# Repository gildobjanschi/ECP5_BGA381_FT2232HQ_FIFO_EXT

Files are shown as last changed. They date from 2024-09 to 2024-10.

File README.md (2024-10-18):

# Extension board for ECP5_BGA381_FT2232HQ_FIFO
This is an extension board for the [ECP5_BGA381_FT2232HQ_FIFO](https://github.com/gildobjanschi/ECP5_BGA381_FT2232HQ_FIFO) board. It is used to validate the main board design and to provide audio output connectors for I2S (HDMI) and SPDIF (Coaxial).

## Software
The bringup software that supports this board is located in the main board [ECP5_BGA381_FT2232HQ_FIFO](https://github.com/gildobjanschi/ECP5_BGA381_FT2232HQ_FIFO/tree/main/hdl_loopback) project. The [host software](https://github.com/gildobjanschi/ECP5_BGA381_FT2232HQ_FIFO/tree/main/host_loopback) is a simple application for testing the FIFO interface.

## Project Status
The board has been submitted to manufacturing to PCBWay.

[Schematic PDF](https://github.com/gildobjanschi/ECP5_BGA381_FT2232HQ_FIFO_EXT/blob/main/kicad/ECP5_Ext.pdf)

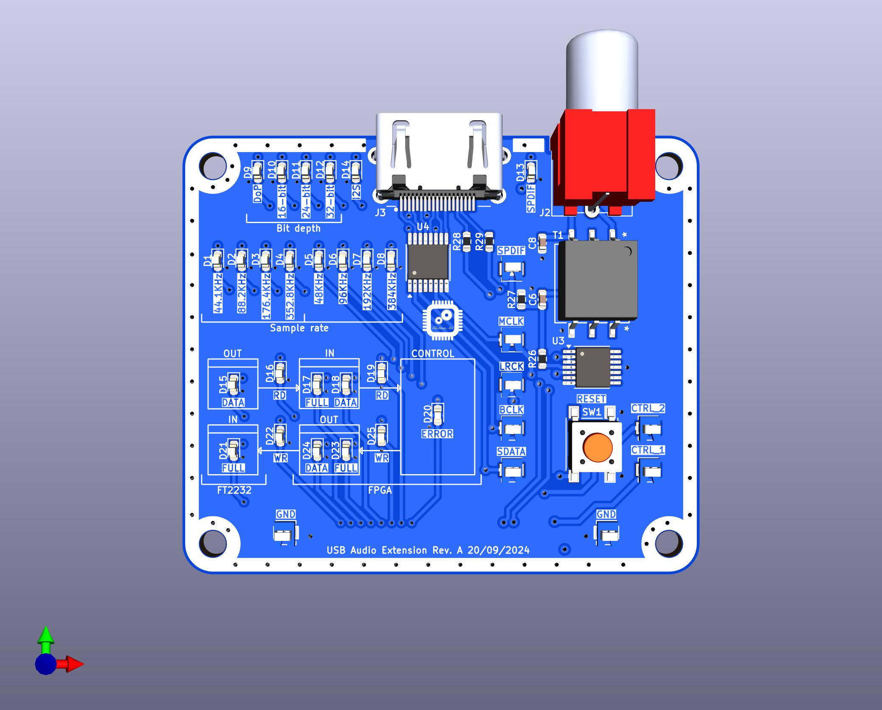
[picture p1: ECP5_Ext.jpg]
Board rendering


## How To setup KiCAD
Checkout the KiCAD project and open it. In the Configure Paths dialog add: Name: ECP5_BGA381_FT2232HQ_FIFO_EXT and Path: "The full path to the GitHub directory"/GitHub/ECP5_BGA381_FT2232HQ_FIFO_EXT

In the Manage Symbol Libraries click the Project Specific Libraries tab and add: Name: ECP5_BGA381_FT2232HQ_FIFO_EXT and Library Path: ${ECP5_BGA381_FT2232HQ_FIFO_EXT}/symbols/Symbols.kicad_sym

In the Manage Footprint Libraries click the Project Specific Libraries tab and add: Name: ECP5_BGA381_FT2232HQ_FIFO_EXT and Library Path: ${ECP5_BGA381_FT2232HQ_FIFO_EXT}/footprints/Footprints.pretty

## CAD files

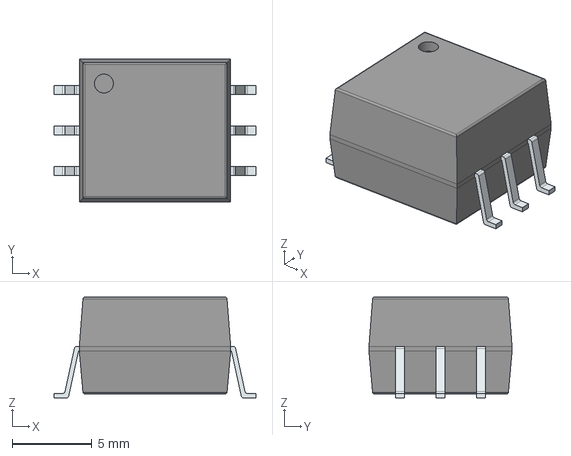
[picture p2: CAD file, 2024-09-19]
3dmodels/DA101JC.stp
12.7 x 9.00 x 6.35 mm
PinsArrayLR

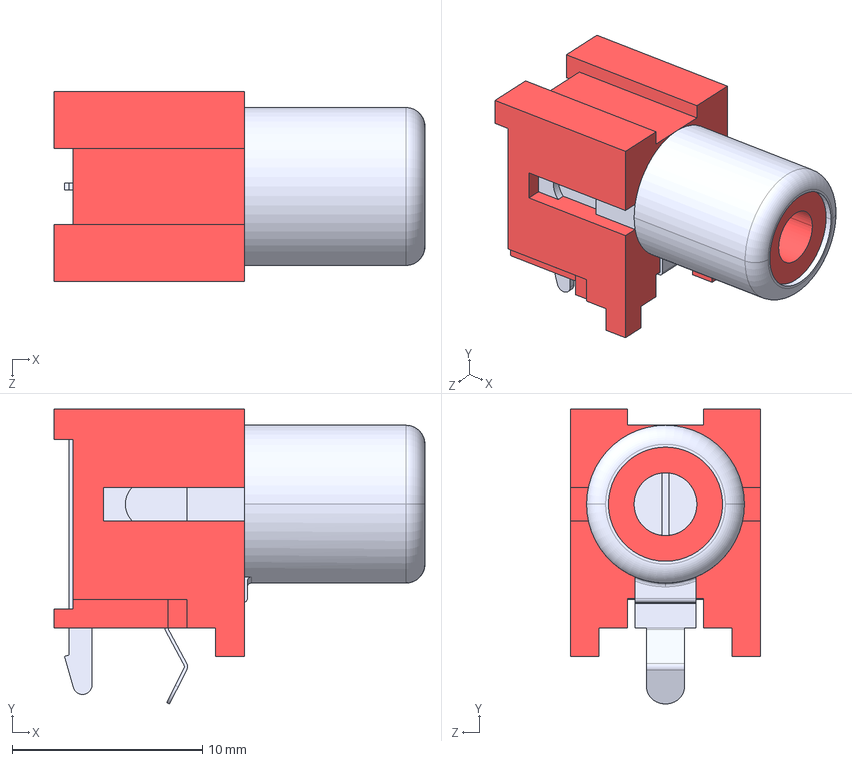
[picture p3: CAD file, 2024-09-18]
3dmodels/RCJ-042.step
19.5 x 15.5 x 10.0 mm

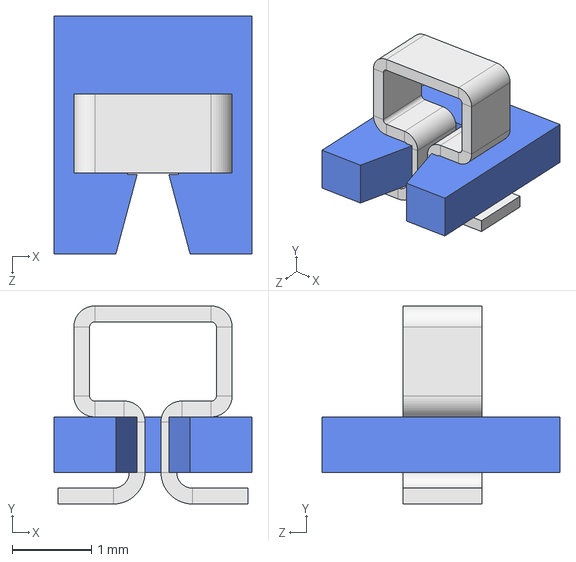
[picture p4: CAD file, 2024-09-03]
3dmodels/5197TR.step
2.50 x 2.50 x 3.00 mm
5197_insulation
5190_assembled contact

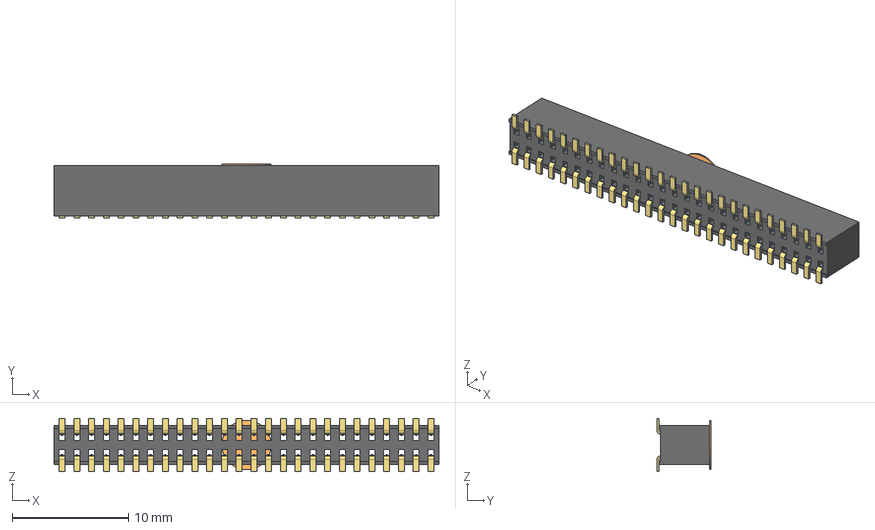
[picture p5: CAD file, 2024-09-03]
3dmodels/FLE-126-01-G-DV-K-TR.stp
33.1 x 4.67 x 4.59 mm
FLE-126-01-DV_socket
C-96-01-26-DV
K-DOT-0.1675-0.281-0.005_polyamide_pick

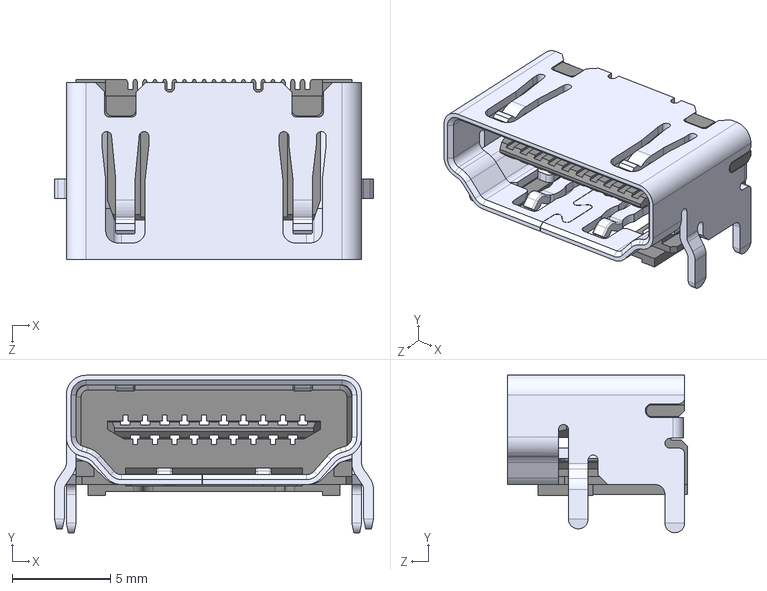
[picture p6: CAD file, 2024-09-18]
3dmodels/10029449-001RLF.step
16.2 x 8.00 x 9.15 mm

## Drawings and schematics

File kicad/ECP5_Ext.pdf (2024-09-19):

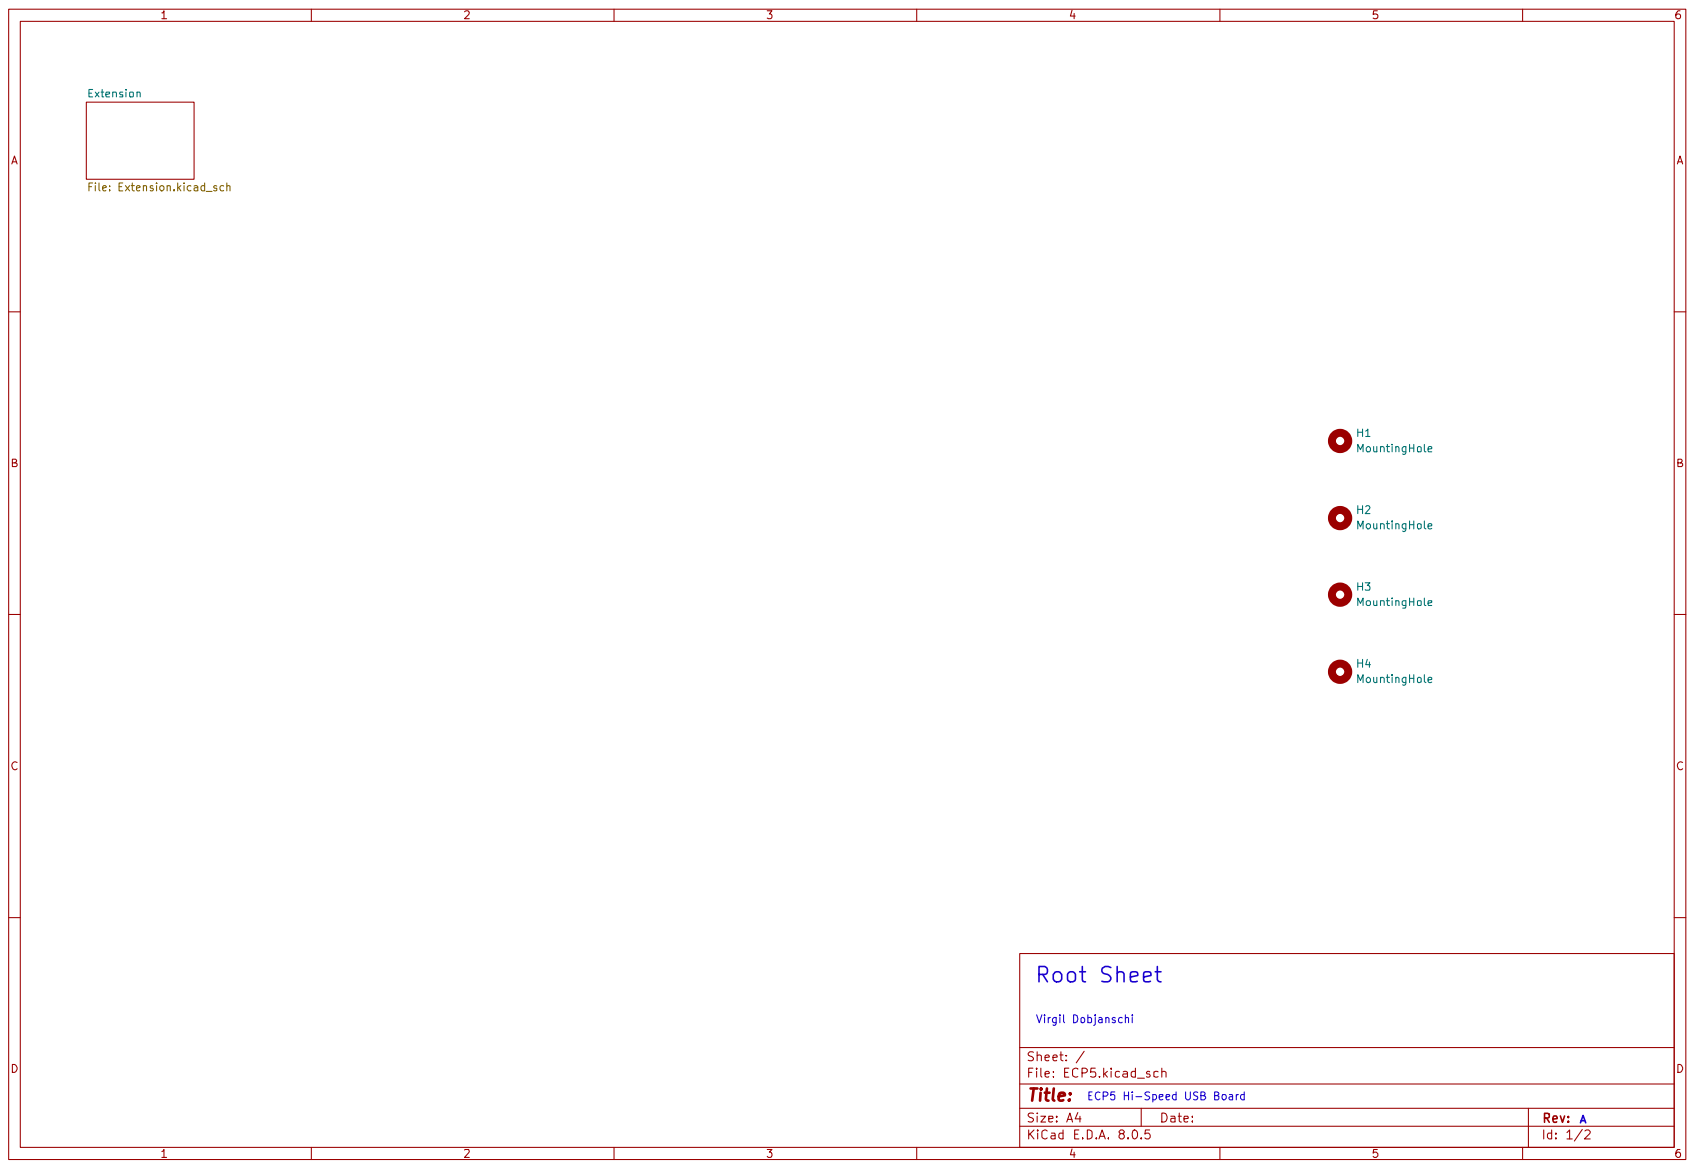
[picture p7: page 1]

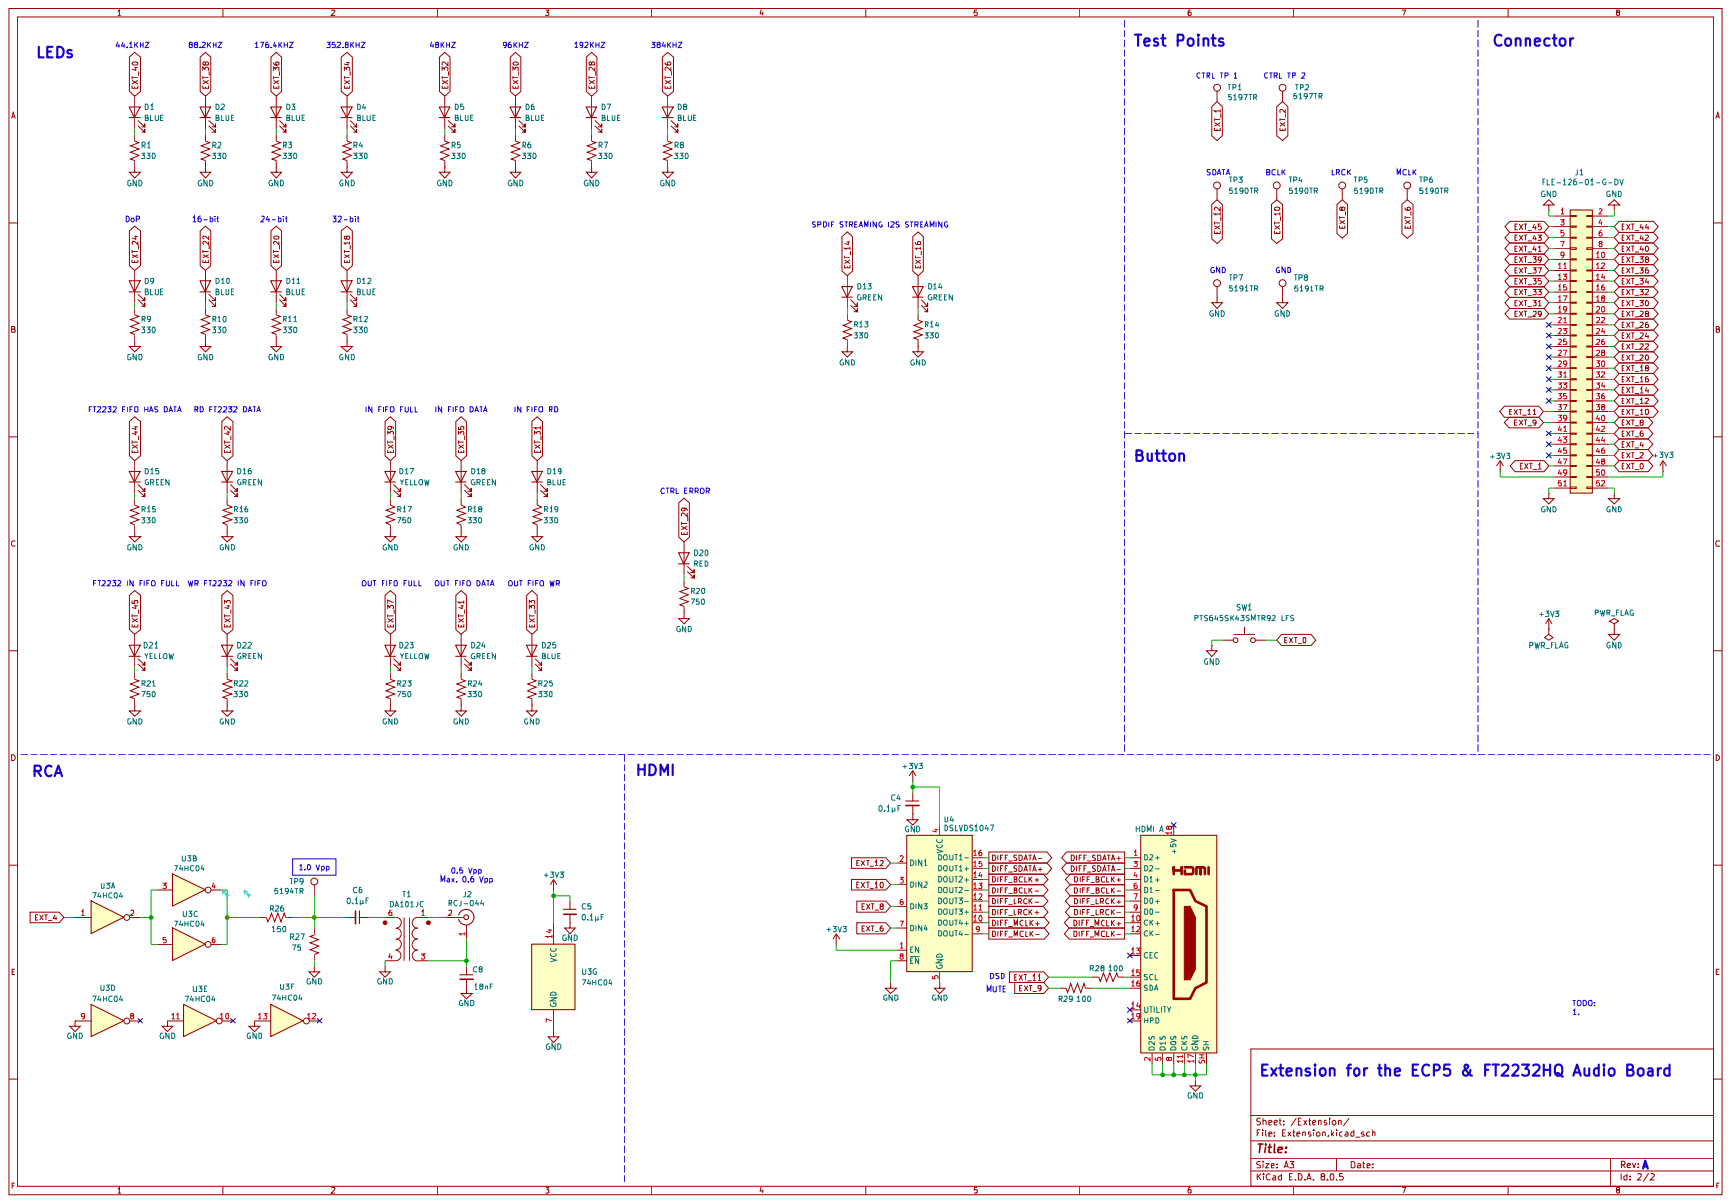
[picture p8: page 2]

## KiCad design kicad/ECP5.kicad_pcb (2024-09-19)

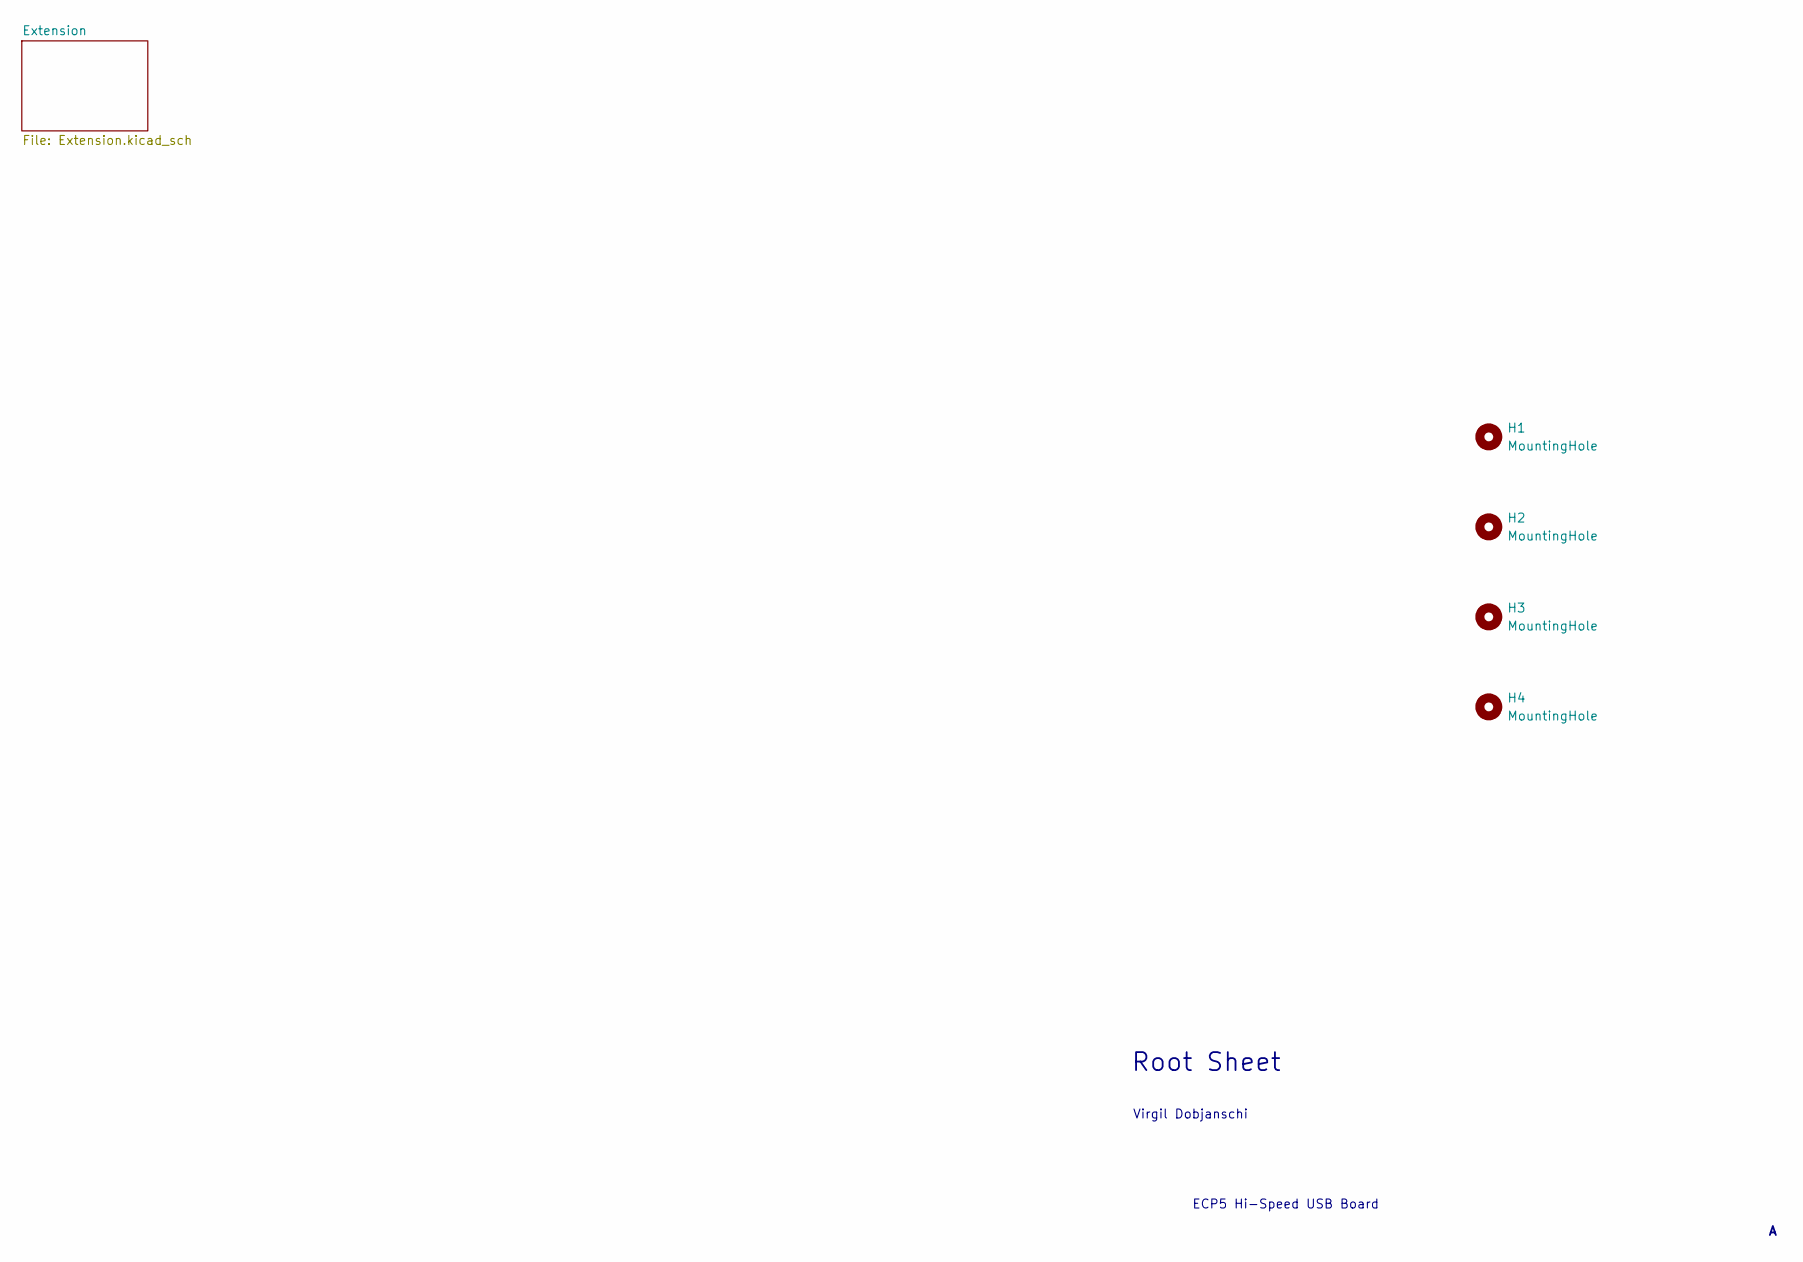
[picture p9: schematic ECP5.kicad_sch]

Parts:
H1, H2, H3, H4: MountingHole; MountingHole_3.2mm_M3

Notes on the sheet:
ECP5 Hi-Speed USB Board
Root Sheet
Virgil Dobjanschi

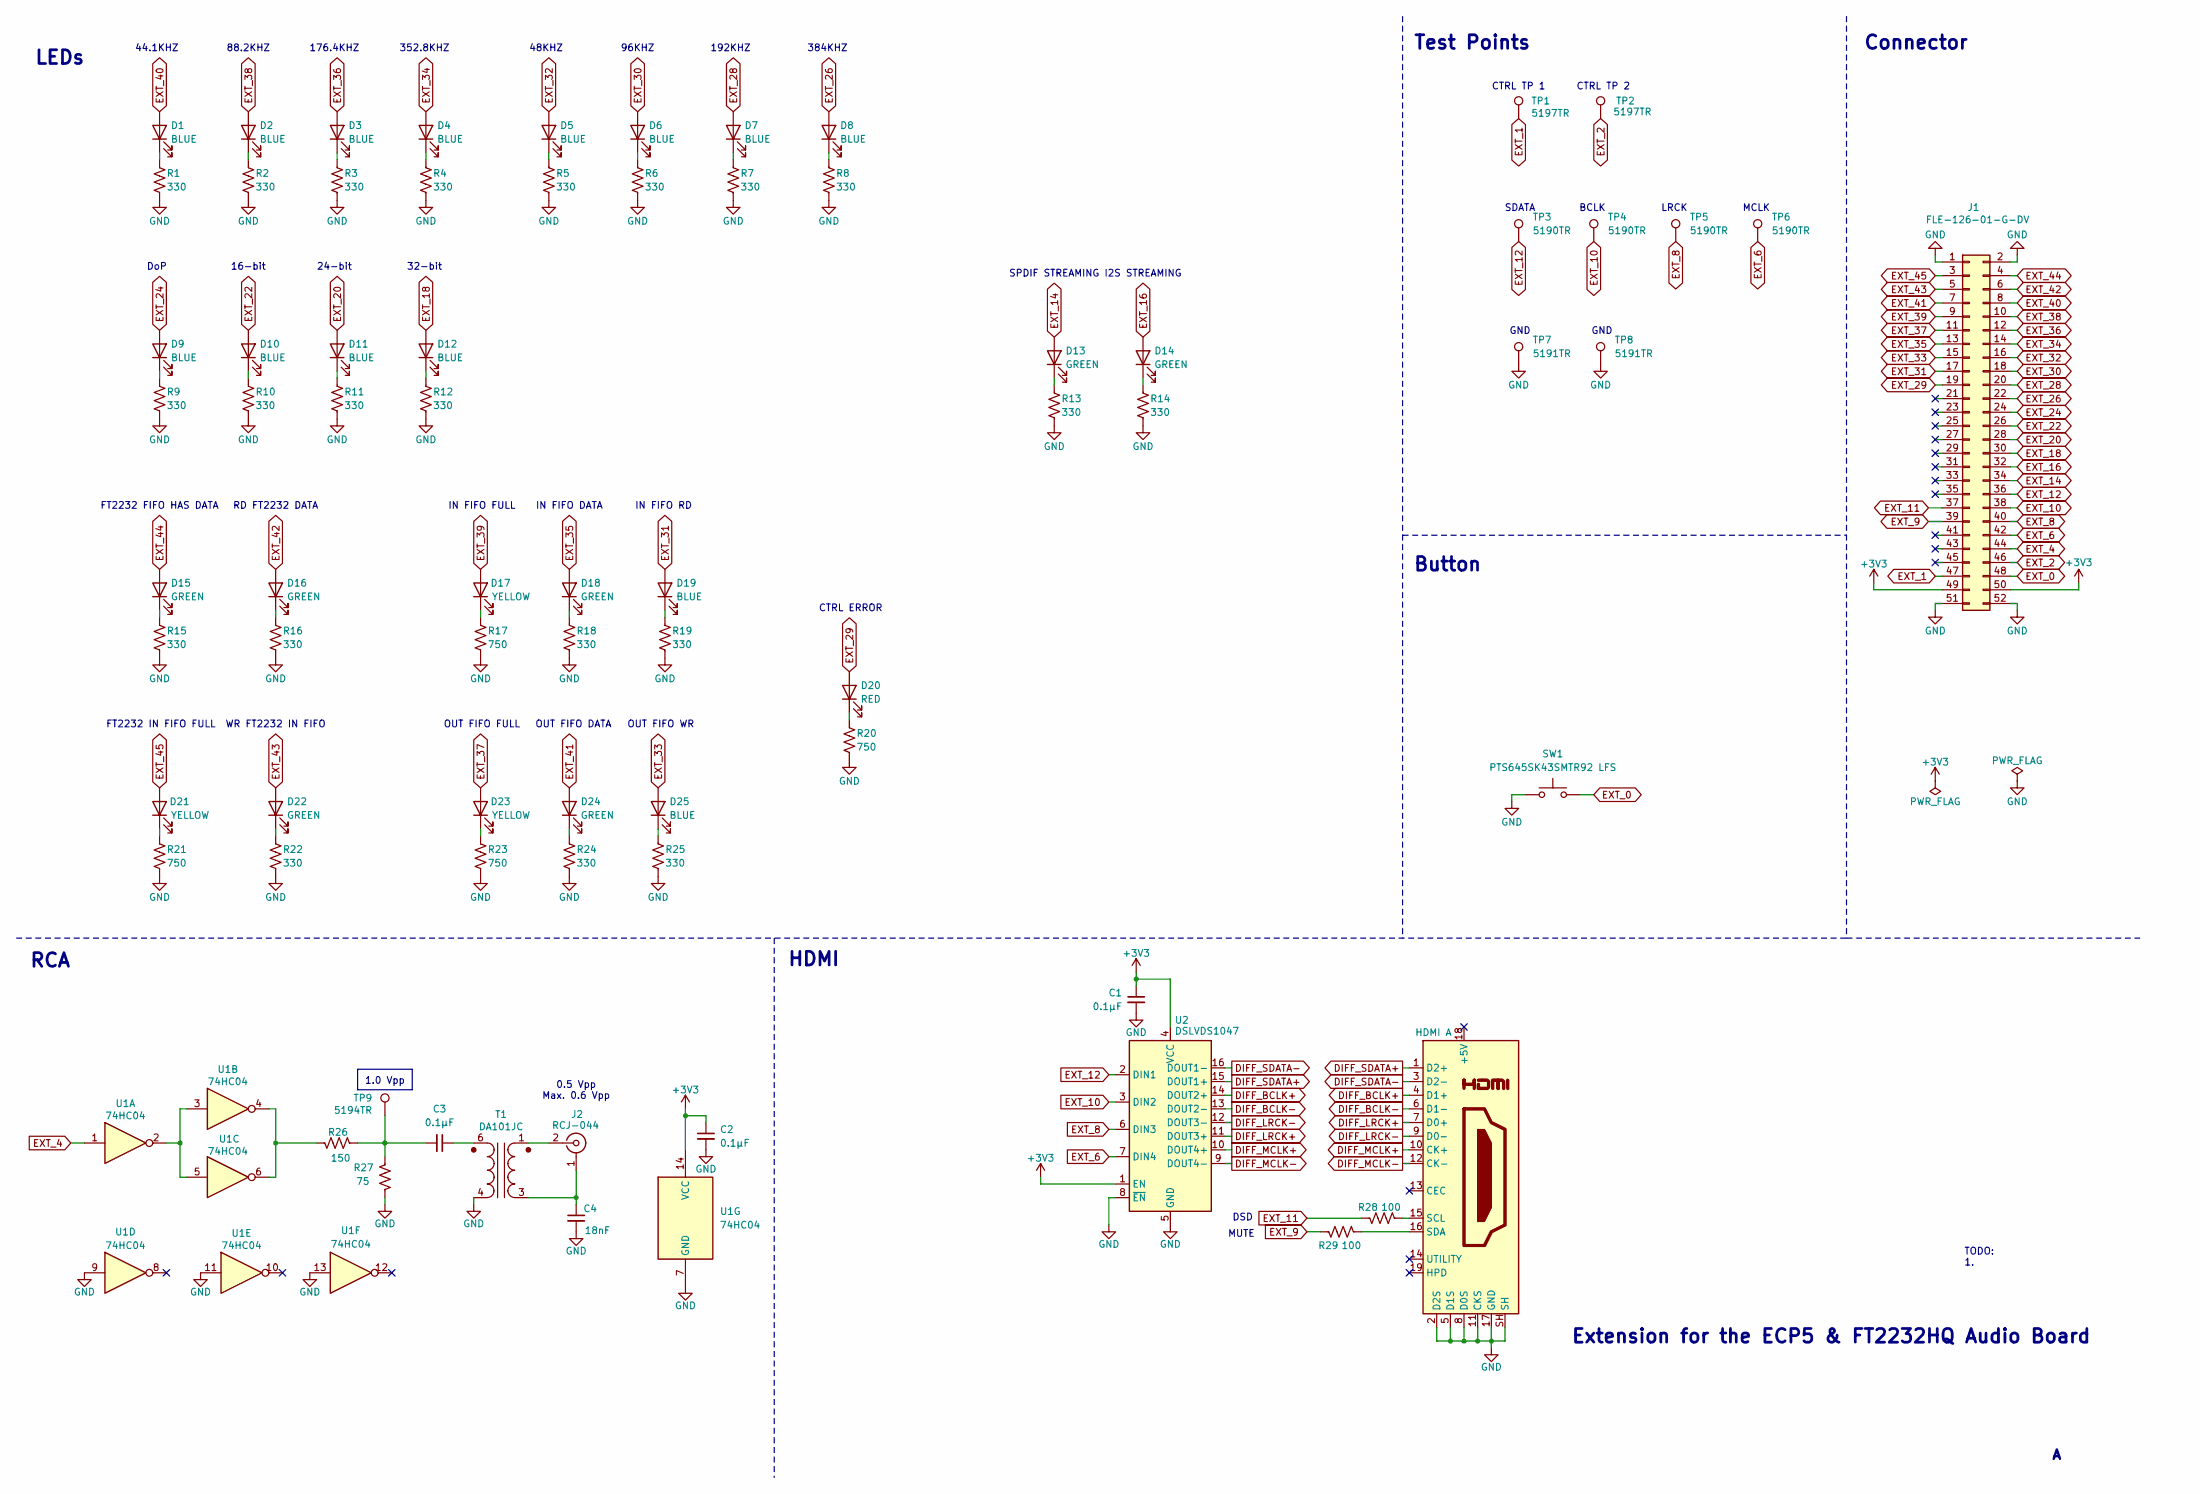
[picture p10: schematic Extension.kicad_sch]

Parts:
C1, C2, C3: 0.1µF; C_0603_1608Metric; MPN CL10B104KB8NNNC
C4: 18nF; C_0603_1608Metric; MPN CC0603KRX7R9BB183
D1, D2, D3, D4, D5, D6, D7, D8, D9, D10, D11, D12, D19, D25: BLUE; LED_0603_1608Metric; MPN APT1608LVBC/D
D13, D14, D15, D16, D18, D22, D24: GREEN; LED_0603_1608Metric; MPN APT1608LZGCK
D17, D21, D23: YELLOW; LED_0603_1608Metric; MPN APT1608LSYCK/J3-PRV
D20: RED; LED_0603_1608Metric; MPN APT1608LSECK/J3-PRV
J1: FLE-126-01-G-DV; SAMTEC_FLE-126-01-G-DV; MPN FLE-126-01-G-DV
J2: RCJ-044; CUI_RCJ-042; MPN RCJ-044
J3: HDMI A; AMPHENOL_10029449-001RLF; MPN 10029449-001RLF
R1, R2, R3, R4, R5, R6, R7, R8, R9, R10, R11, R12, R13, R14, R15, R16, R18, R19, R22, R24, R25: 330; R_0603_1608Metric; MPN ERJ-3EKF3300V
R17, R20, R21, R23: 750; R_0603_1608Metric; MPN ERJ-3EKF7500V
R26: 150; R_0603_1608Metric; MPN ERJ-3EKF1500V
R27: 75; R_0603_1608Metric; MPN ERJ-3EKF75R0V
R28, R29: 100; R_0603_1608Metric; MPN ERJ-3EKF1000V
SW1: PTS645SK43SMTR92 LFS; SW_SPST_PTS645; MPN PTS645SK43SMTR92 LFS
T1: DA101JC; DA101J_MUR; MPN DA101JC
TP1, TP2: 5197TR; KEYSTONE_5197TR; MPN 5197TR
TP3, TP4, TP5, TP6: 5190TR; KEYSTONE_5197TR; MPN 5190TR
TP7, TP8: 5191TR; KEYSTONE_5197TR; MPN 5191TR
TP9: 5194TR; KEYSTONE_5197TR; MPN 5194TR
U1: 74HC04; TSSOP-14_4.4x5mm_P0.65mm; MPN SN74HC04PWR
U2: DSLVDS1047; TSSOP-16-1EP_4.4x5mm_P0.65mm; MPN DSLVDS1047PWR

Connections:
+3V3: C1.1, C2.1, J1.49, J1.50, U1.14 (VCC), U2.1 (EN), U2.4 (VCC)
DIFF_BCLK+: J3.4 (D1+), U2.14 (DOUT2+)
DIFF_BCLK-: J3.6 (D1-), U2.13 (DOUT2-)
DIFF_LRCK+: J3.7 (D0+), U2.11 (DOUT3+)
DIFF_LRCK-: J3.9 (D0-), U2.12 (DOUT3-)
DIFF_MCLK+: J3.10 (CK+), U2.10 (DOUT4+)
DIFF_MCLK-: J3.12 (CK-), U2.9 (DOUT4-)
DIFF_SDATA+: J3.1 (D2+), U2.15 (DOUT1+)
DIFF_SDATA-: J3.3 (D2-), U2.16 (DOUT1-)
EXT_0: J1.48, SW1.2
EXT_1: J1.47, TP1.1
EXT_2: J1.46, TP2.1
EXT_4: J1.44, U1.1
EXT_6: J1.42, TP6.1, U2.7 (DIN4)
EXT_8: J1.40, TP5.1, U2.6 (DIN3)
EXT_9: J1.39, R29.2
EXT_10: J1.38, TP4.1, U2.3 (DIN2)
EXT_11: J1.37, R28.2
EXT_12: J1.36, TP3.1, U2.2 (DIN1)
EXT_14: D13.2 (A), J1.34
EXT_16: D14.2 (A), J1.32
EXT_18: D12.2 (A), J1.30
EXT_20: D11.2 (A), J1.28
EXT_22: D10.2 (A), J1.26
EXT_24: D9.2 (A), J1.24
EXT_26: D8.2 (A), J1.22
EXT_28: D7.2 (A), J1.20
EXT_29: D20.2 (A), J1.19
EXT_30: D6.2 (A), J1.18
EXT_31: D19.2 (A), J1.17
EXT_32: D5.2 (A), J1.16
EXT_33: D25.2 (A), J1.15
EXT_34: D4.2 (A), J1.14
EXT_35: D18.2 (A), J1.13
EXT_36: D3.2 (A), J1.12
EXT_37: D23.2 (A), J1.11
EXT_38: D2.2 (A), J1.10
EXT_39: D17.2 (A), J1.9
EXT_40: D1.2 (A), J1.8
EXT_41: D24.2 (A), J1.7
EXT_42: D16.2 (A), J1.6
EXT_43: D22.2 (A), J1.5
EXT_44: D15.2 (A), J1.4
EXT_45: D21.2 (A), J1.3
GND: C1.2, C2.2, C4.2, J1.1, J1.2, J1.51, J1.52, J3.2 (D2S), J3.5 (D1S), J3.8 (D0S), J3.11 (CKS), J3.17 (GND), J3.SH, R1.2, R2.2, R3.2, R4.2, R5.2, R6.2, R7.2, R8.2, R9.2, R10.2, R11.2, R12.2, R13.2, R14.2, R15.2, R16.2, R17.2, R18.2, R19.2, R20.2, R21.2, R22.2, R23.2, R24.2, R25.2, R27.2, SW1.1, T1.4 (SA), TP7.1, TP8.1, U1.7 (GND), U1.9, U1.11, U1.13, U2.5 (GND), U2.8 (~EN)
unnamed: C3.2, R26.1, R27.1, TP9.1
unnamed: D1.1 (K), R1.1
unnamed: D2.1 (K), R2.1
unnamed: D3.1 (K), R3.1
unnamed: D4.1 (K), R4.1
unnamed: D5.1 (K), R5.1
unnamed: D6.1 (K), R6.1
unnamed: D7.1 (K), R7.1
unnamed: D8.1 (K), R8.1
unnamed: D9.1 (K), R9.1
unnamed: D10.1 (K), R10.1
unnamed: D11.1 (K), R11.1
unnamed: D12.1 (K), R12.1
unnamed: D13.1 (K), R13.1
unnamed: D14.1 (K), R14.1
unnamed: D15.1 (K), R15.1
unnamed: D16.1 (K), R16.1
unnamed: D17.1 (K), R17.1
unnamed: D18.1 (K), R18.1
unnamed: D19.1 (K), R19.1
unnamed: D20.1 (K), R20.1
unnamed: D21.1 (K), R21.1
unnamed: D22.1 (K), R22.1
unnamed: D23.1 (K), R23.1
unnamed: D24.1 (K), R24.1
unnamed: D25.1 (K), R25.1
unnamed: C4.1, J2.1 (Ext), T1.3 (AB)
unnamed: J2.2 (In), T1.1 (AA)
unnamed: J3.15 (SCL), R28.1
unnamed: J3.16 (SDA), R29.1
unnamed: R26.2, U1.4, U1.6
unnamed: C3.1, T1.6 (SB)
unnamed: U1.2, U1.3, U1.5

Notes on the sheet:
24-bit
RCA
48KHZ
HDMI
IN FIFO DATA
SDATA
BCLK
DSD
192KHZ
FT2232 FIFO HAS DATA
CTRL TP 2
TODO: 1.
352.8KHZ
CTRL TP 1
Connector
RD FT2232 DATA
Button
IN FIFO RD
Test Points
GND
1.0 Vpp
OUT FIFO DATA
OUT FIFO WR
OUT FIFO FULL
44.1KHZ
176.4KHZ
96KHZ
FT2232 IN FIFO FULL
0.5 Vpp Max. 0.6 Vpp
CTRL ERROR
MCLK
Extension for the ECP5 & FT2232HQ Audio Board
SPDIF STREAMING
16-bit
WR FT2232 IN FIFO
LRCK
32-bit
384KHZ
I2S STREAMING
88.2KHZ

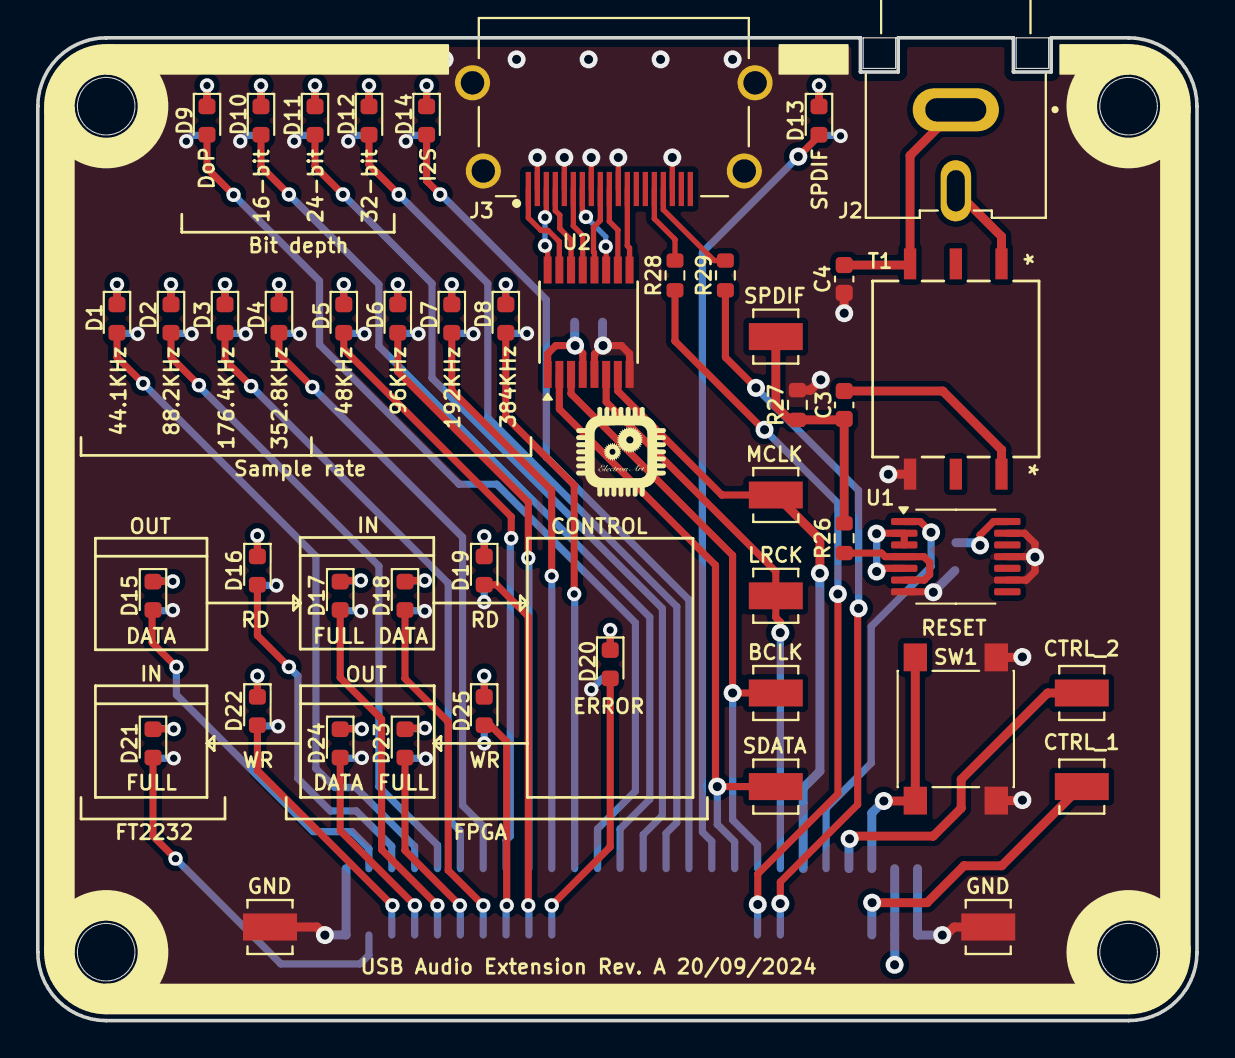
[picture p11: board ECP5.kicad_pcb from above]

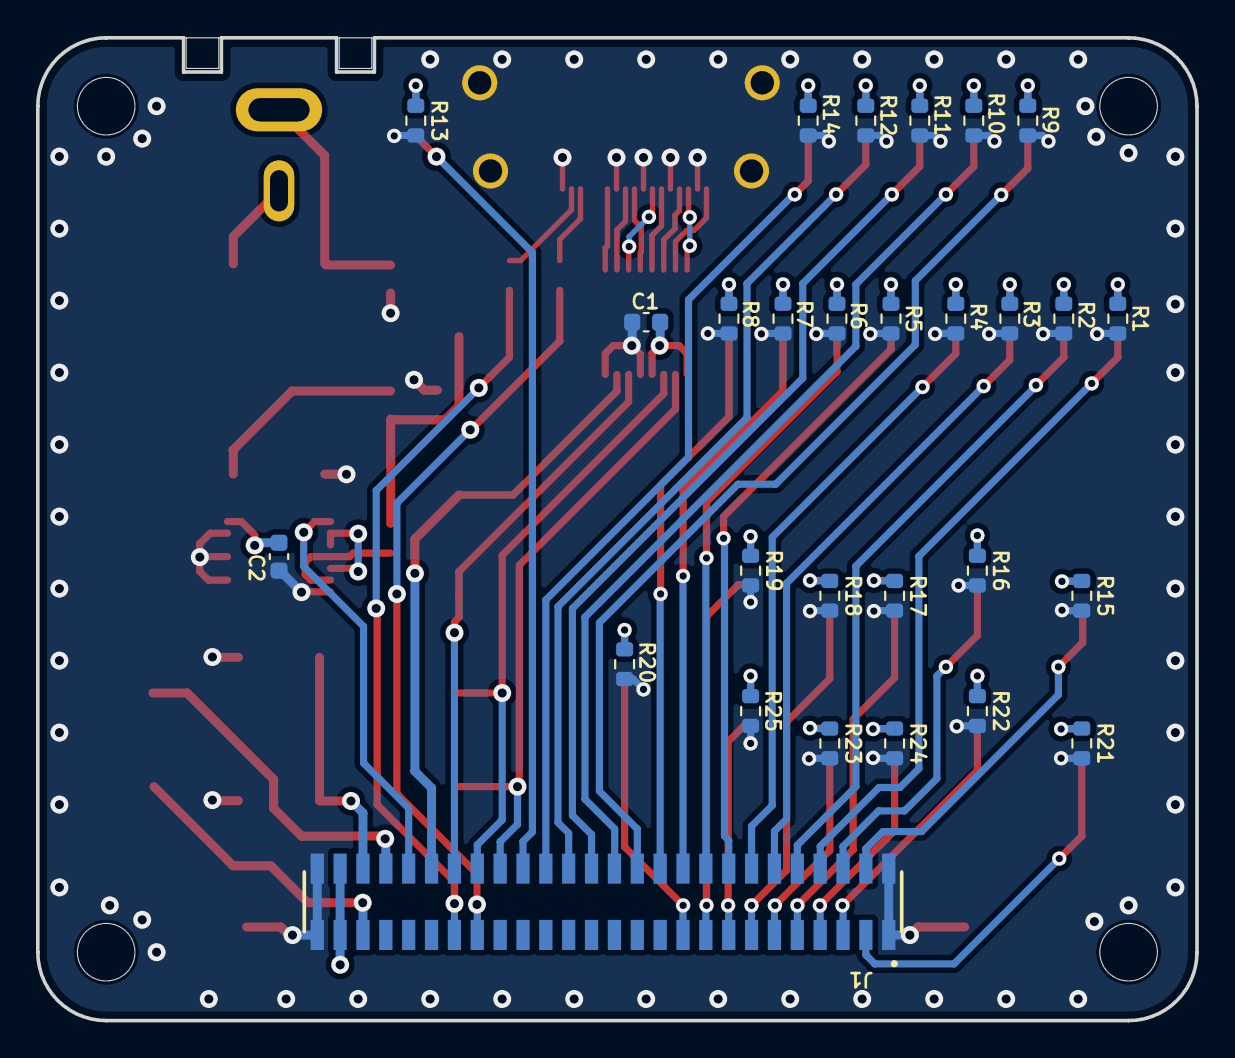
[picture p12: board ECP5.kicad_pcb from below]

Board: 4 copper layers, 64.4 x 54.6 mm, 78 parts (28 on the bottom side), 78 nets.

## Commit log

2024-09-06 Changed the name of the project path to ECP5_BGA381_FT2232HQ_FIFO_EXT
    [ECP5.kicad_pcb, Extension.kicad_sch]
2024-09-18 First pass at arranging components
    [10029449-001RLF.step, ECP5.kicad_pcb, ECP5.kicad_sch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]
2024-09-18 Updated the BOM
    [ECP5.kicad_pcb, Extension.kicad_sch]
2024-09-19 Removed unused symbols and footprints
    [DA101JC.stp, ECP5.kicad_pcb, Extension.kicad_sch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]
2024-09-19 First routing
    [ECP5.kicad_pcb, Extension.kicad_sch]
2024-09-19 Added schematics pdf
2024-09-19 Updated PCB
    [ECP5.kicad_pcb]
2024-10-18 Added measurements
    [Extension.kicad_sch]

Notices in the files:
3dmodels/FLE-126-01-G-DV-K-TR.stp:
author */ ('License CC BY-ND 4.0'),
